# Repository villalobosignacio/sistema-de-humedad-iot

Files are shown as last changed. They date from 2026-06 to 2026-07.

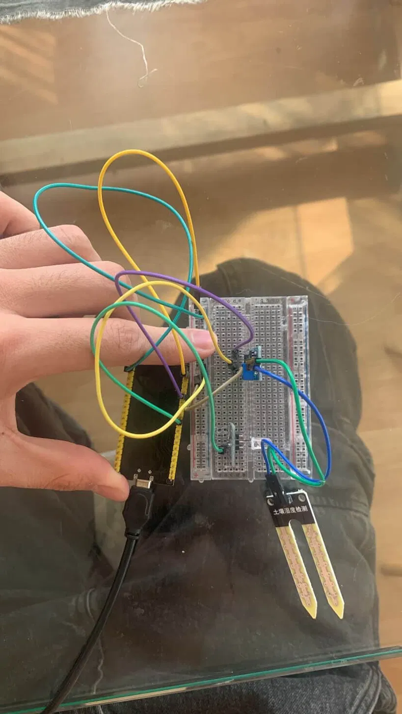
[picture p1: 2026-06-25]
hardware/1 foto.webp

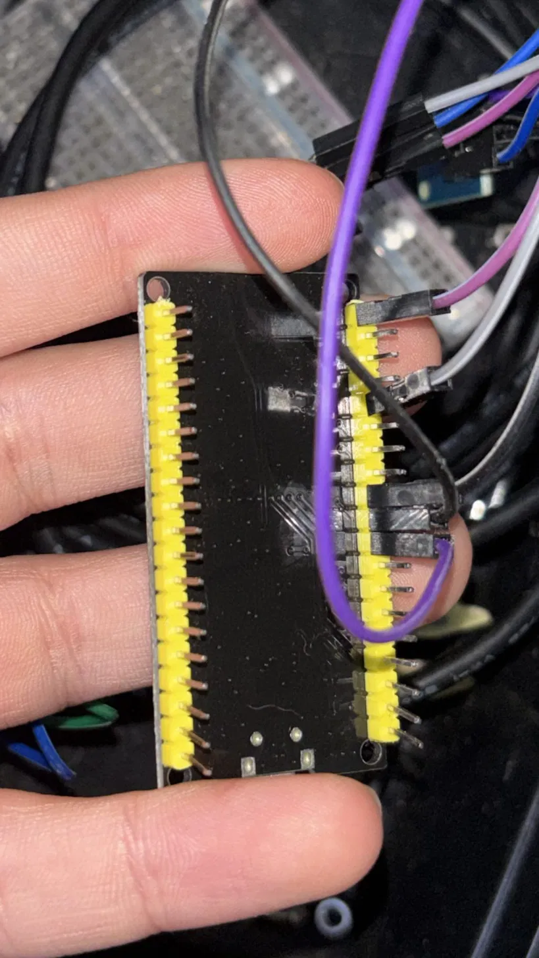
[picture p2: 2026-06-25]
hardware/2 foto.webp

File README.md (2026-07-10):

Sistema de Monitoreo de Humedad de Suelo

Sistema IoT que monitorea la humedad del suelo en tiempo real mediante un sensor resistivo conectado a un ESP32. El dispositivo indica el estado del suelo a través de LEDs de colores y registra las lecturas en el monitor serie, permitiendo tomar decisiones de riego oportunas.

Integrantes
Nicolas Oliden 
Benjamin Pizarro 
Ignacio Villalobos 
Emmanuel Poulangeon 

Curso: TEI201 — Taller de Diseño en Ingeniería  
Universidad: Universidad Adolfo Ibáñez  
Año:2026

Problema que resuelve

En hogares y espacios urbanos de Chile, el riego de plantas se realiza de forma intuitiva y sin información objetiva sobre el estado real del suelo. Esto genera dos problemas frecuentes: el riego excesivo, que desperdicia agua y daña las raíces por saturación, y la falta de riego oportuno, que provoca la muerte de las plantas. Nuestro sistema elimina esta incertidumbre entregando una señal visual inmediata sobre el nivel de humedad del suelo, permitiendo al usuario regar solo cuando es necesario.  
El sistema permite a cualquier persona saber si una planta necesita riego sin necesidad de medir manualmente la humedad del suelo. Un LED rojo indica tierra seca (riego urgente), amarillo indica humedad media, y verde indica tierra bien regada.

Componentes de hardware necesarios

| Componente | Cantidad | Especificación |

Componentes de hardware necesarios

| Componente | Cantidad | Especificación |
| ESP32 NodeMCU | 1 | microcontrolador con Wi-Fi integrado, ADC 12-bit |
| Sensor humedad suelo | 1 | Módulo LM393 (Sonda resistiva) — Conectado a pin GPIO 34 |
| Protoboard 400 pts | 1 | Para el montaje y orden de conexiones internas |
| Cables jumper | 10 | Conexiones internas de señal y alimentación |
| Cable USB micro | 1 | Para suministro eléctrico continuo y programación |
| Filamento PLA | ~50g | Material para la manufactura de la carcasa protectora 3D |

Ver BOM completo con costos en `/hardware/BOM.md`

Instrucciones para cargar el firmware

Requisitos previos
Arduino IDE 2.x instalado
Soporte para ESP32 instalado en el Board Manager:
Ir a **Archivo → Preferencias**
En "URLs adicionales" agregar: `https://raw.githubusercontent.com/espressif/arduino-esp32/gh-pages/package_esp32_index.json`
Ir a Herramientas → Placa → Gestor de placas → buscar "esp32" → Instalar

Pasos
1. Clonar este repositorio:
   ```
   git clone https://github.com/villalobosignacio/sistema-de-humedad-iot.git
   ```
2. Abrir `firmware/main.ino` en Arduino IDE
3. Conectar el ESP32 por USB
4. Seleccionar la placa: Herramientas → Placa → ESP32 Arduino → ESP32 Dev Module
5. Seleccionar el puerto COM correspondiente en Herramientas → Puerto
6. Subir el código con el botón Upload(→)
7. Abrir Monitor Serie a 115200 baudios para ver las lecturas en tiempo real

Lógica de indicación LED

| Color LED | Valor ADC | Estado del suelo |

| Rojo | 3000 – 4095 | Tierra seca — necesita riego |
| Amarillo (R+G) | 2000 – 2999 | Humedad media |
| Verde | 0 – 1999 | Tierra húmeda / bien irrigada |

Dashboard y Visualización
Los datos capturados por el ESP32 se envían mediante peticiones HTTPS (POST) a nuestra propia API alojada en Railway. 

[Acceder a la API/Dashboard en Railway](https://sistema-de-humedad-iot-production.up.railway.app/api/medicion)

Estructura del repositorio

```
sistema-de-humedad-iot/
│
├── README.md
├── FUENTES.md
│
├── firmware/
│   └── main.ino
│
├── hardware/
│   ├── BOM.md
│   ├── esquematico.pdf
│   ├── foto_prototipo_1.jpg
│   ├── foto_prototipo_2.jpg
│   └── foto_prototipo_3.jpg
│
├── diseño-3d/
│   ├── encapsulado.f3d
│   ├── planos.pdf
│   └── renders/
│
├── testing/
│   └── protocolo_pruebas.md
│
└── docs/
    └── reporte_final.pdf
```

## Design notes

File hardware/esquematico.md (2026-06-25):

Esquemático del circuito

Diagrama interactivo en Wokwi (incluye ESP32, sensor de humedad y LEDs):

Esquemático en Wokwi:https://wokwi.com/projects/462746890644844545

Componentes conectados
ESP32 NodeMCU
Sensor de humedad resistivo → GPIO34
LED Rojo → GPIO25 + resistencia 220Ω
LED Verde → GPIO26 + resistencia 220Ω  
LED Azul → GPIO27 + resistencia 220Ω

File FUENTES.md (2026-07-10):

Declaración de Fuentes y Herramientas

Proyecto: Sistema de Monitoreo de Humedad de Suelo IoT
Curso: TEI201 — Taller de Diseño en Ingeniería
Integrantes: Nicolas Oliden, Benjamin Pizarro, Ignacio Villalobos, Emmanuel Poulangeon

1. Librerías utilizadas

El proyecto utiliza las siguientes librerías del núcleo de ESP32 para habilitar la lectura analógica y la conectividad a internet:

| Función / Módulo | Origen | Uso en el proyecto |
| `WiFi.h` | Arduino ESP32 Core | Conexión del microcontrolador a la red Wi-Fi local. |
| `HTTPClient.h` | Arduino ESP32 Core | Creación y envío de peticiones HTTP POST al servidor. |
| `WiFiClientSecure.h` | Arduino ESP32 Core | Manejo de la conexión segura (HTTPS) para interactuar con la API en Railway. |
| `analogRead()` | Arduino ESP32 Core | Lectura del sensor de humedad de suelo en el pin 34. |

2. Código externo adaptado

No se utilizaron fragmentos de código de fuentes externas (GitHub, Stack Overflow, tutoriales, etc.). La estructura de conexión Wi-Fi y las peticiones HTTP fueron desarrolladas por el equipo con asistencia de Inteligencia Artificial.

3. Uso de Inteligencia Artificial

Desarrollo del Firmware (C++)
Herramientas: Claude y Gemini.
Uso:Asistencia en la reestructuración del código para evolucionar de un sistema local a un prototipo IoT conectado. Generación de la lógica para el armado del string JSON y el envío de la petición POST segura (`clienteSeguro.setInsecure()`) a la API alojada en Railway.
Comprensión del equipo: El equipo comprende completamente el flujo de datos: el sensor lee el valor analógico en el pin 34, la función `map()` lo convierte a un porcentaje (0-100%), se construye el payload en formato JSON y se envía mediante protocolo HTTPS a la ruta `/api/medicion`.

Documentación (README.md)
Herramientas: Claude.
Uso: Generación del template base del `README.md`; el contenido técnico específico fue completado por el equipo.

4. Recursos de referencia

| Recurso | URL | Uso |
| Documentación ESP32 Arduino Core | https://docs.espressif.com/projects/arduino-esp32/en/latest/ | Referencia para el pinout del ESP32 y funciones analógicas. |
| Railway Documentation | https://docs.railway.app/ | Referencia para el despliegue y recepción de datos en la API. |

*Declaración preparada en cumplimiento de los requisitos de integridad académica del curso TEI201 — UAI.*

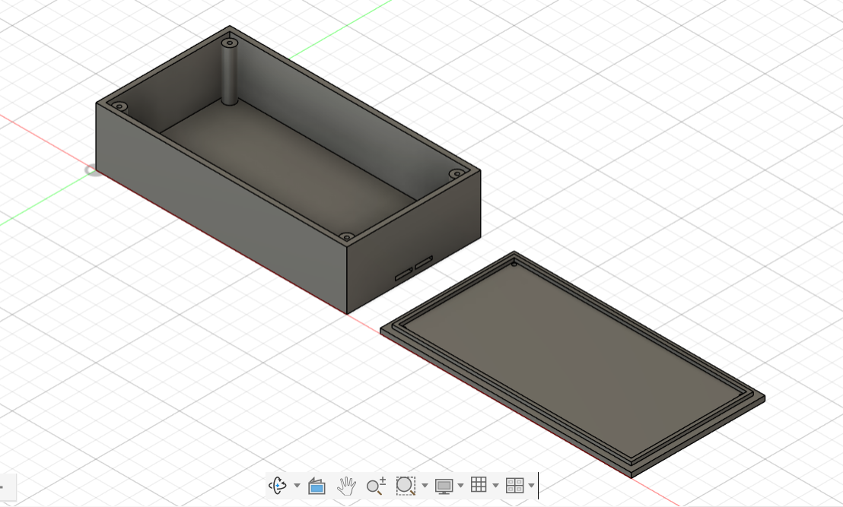
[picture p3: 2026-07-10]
diseño-3d/renders/Captura de pantalla 2026-07-09 182423.png

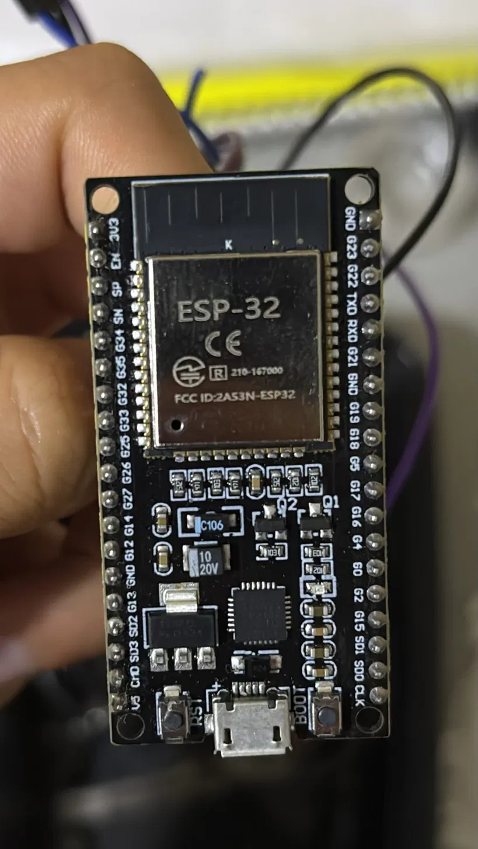
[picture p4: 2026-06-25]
hardware/3 foto.webp

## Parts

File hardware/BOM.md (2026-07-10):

BOM — Lista de Materiales

Proyecto: Sistema de Monitoreo de Humedad de Suelo IoT  
Curso: TEI201 — UAI 2026  
Integrantes: Nicolas Oliden, Benjamin Pizarro, Ignacio Villalobos, Emmanuel Poulangeon

| N° | Componente | Cantidad | Especificación técnica | Costo unitario (CLP) | Costo total (CLP) |
| 1 | ESP32 NodeMCU | 1 | ESP-32 38 pines, Wi-Fi + Bluetooth, dual core 240MHz, ADC 12-bit | $8.500 | $8.500 |
| 2 | Sensor humedad de suelo | 1 | Módulo LM393, salida analógica, rango 0–4095 ADC | $1.800 | $1.800 |
| 3 | Protoboard | 1 | 400 puntos, para montaje de pines internos | $2.500 | $2.500 |
| 4 | Cables jumper | 10 | Macho-hembra / Macho-macho, 20cm | $150 | $1.500 |
| 5 | Cable USB micro | 1 | Micro-USB, datos + alimentación (energía del sistema) | $1.500 | $1.500 |
| 6 | Filamento PLA (Impresión 3D) | ~50g | Material para la manufactura de la carcasa protectora | $20/gramo | $1.000 |
| TOTAL | | | | | $16.800 |

Justificación de componentes principales

ESP32 NodeMCU: Seleccionado estratégicamente por su módulo Wi-Fi integrado, el cual es el núcleo de nuestro sistema IoT. Permite capturar la lectura analógica de la tierra con precisión (ADC de 12 bits) y procesar el envío de datos en formato JSON de forma segura (HTTPS) hacia nuestra API en Railway.
Sensor resistivo de humedad: Seleccionado por disponibilidad, bajo costo y compatibilidad directa con el pin 34 del ESP32. La variación de la conductividad de la tierra se traduce en un nivel de voltaje que el microcontrolador mapea de 0 a 100%.
Carcasa impresa en 3D (PLA): Pieza diseñada a medida y parametrizada para encapsular de forma segura el microcontrolador y el cableado, protegiendo la electrónica y manteniendo expuesta únicamente la sonda que va insertada en el sustrato.

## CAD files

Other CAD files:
diseño-3d/caja sensor examen.f3d

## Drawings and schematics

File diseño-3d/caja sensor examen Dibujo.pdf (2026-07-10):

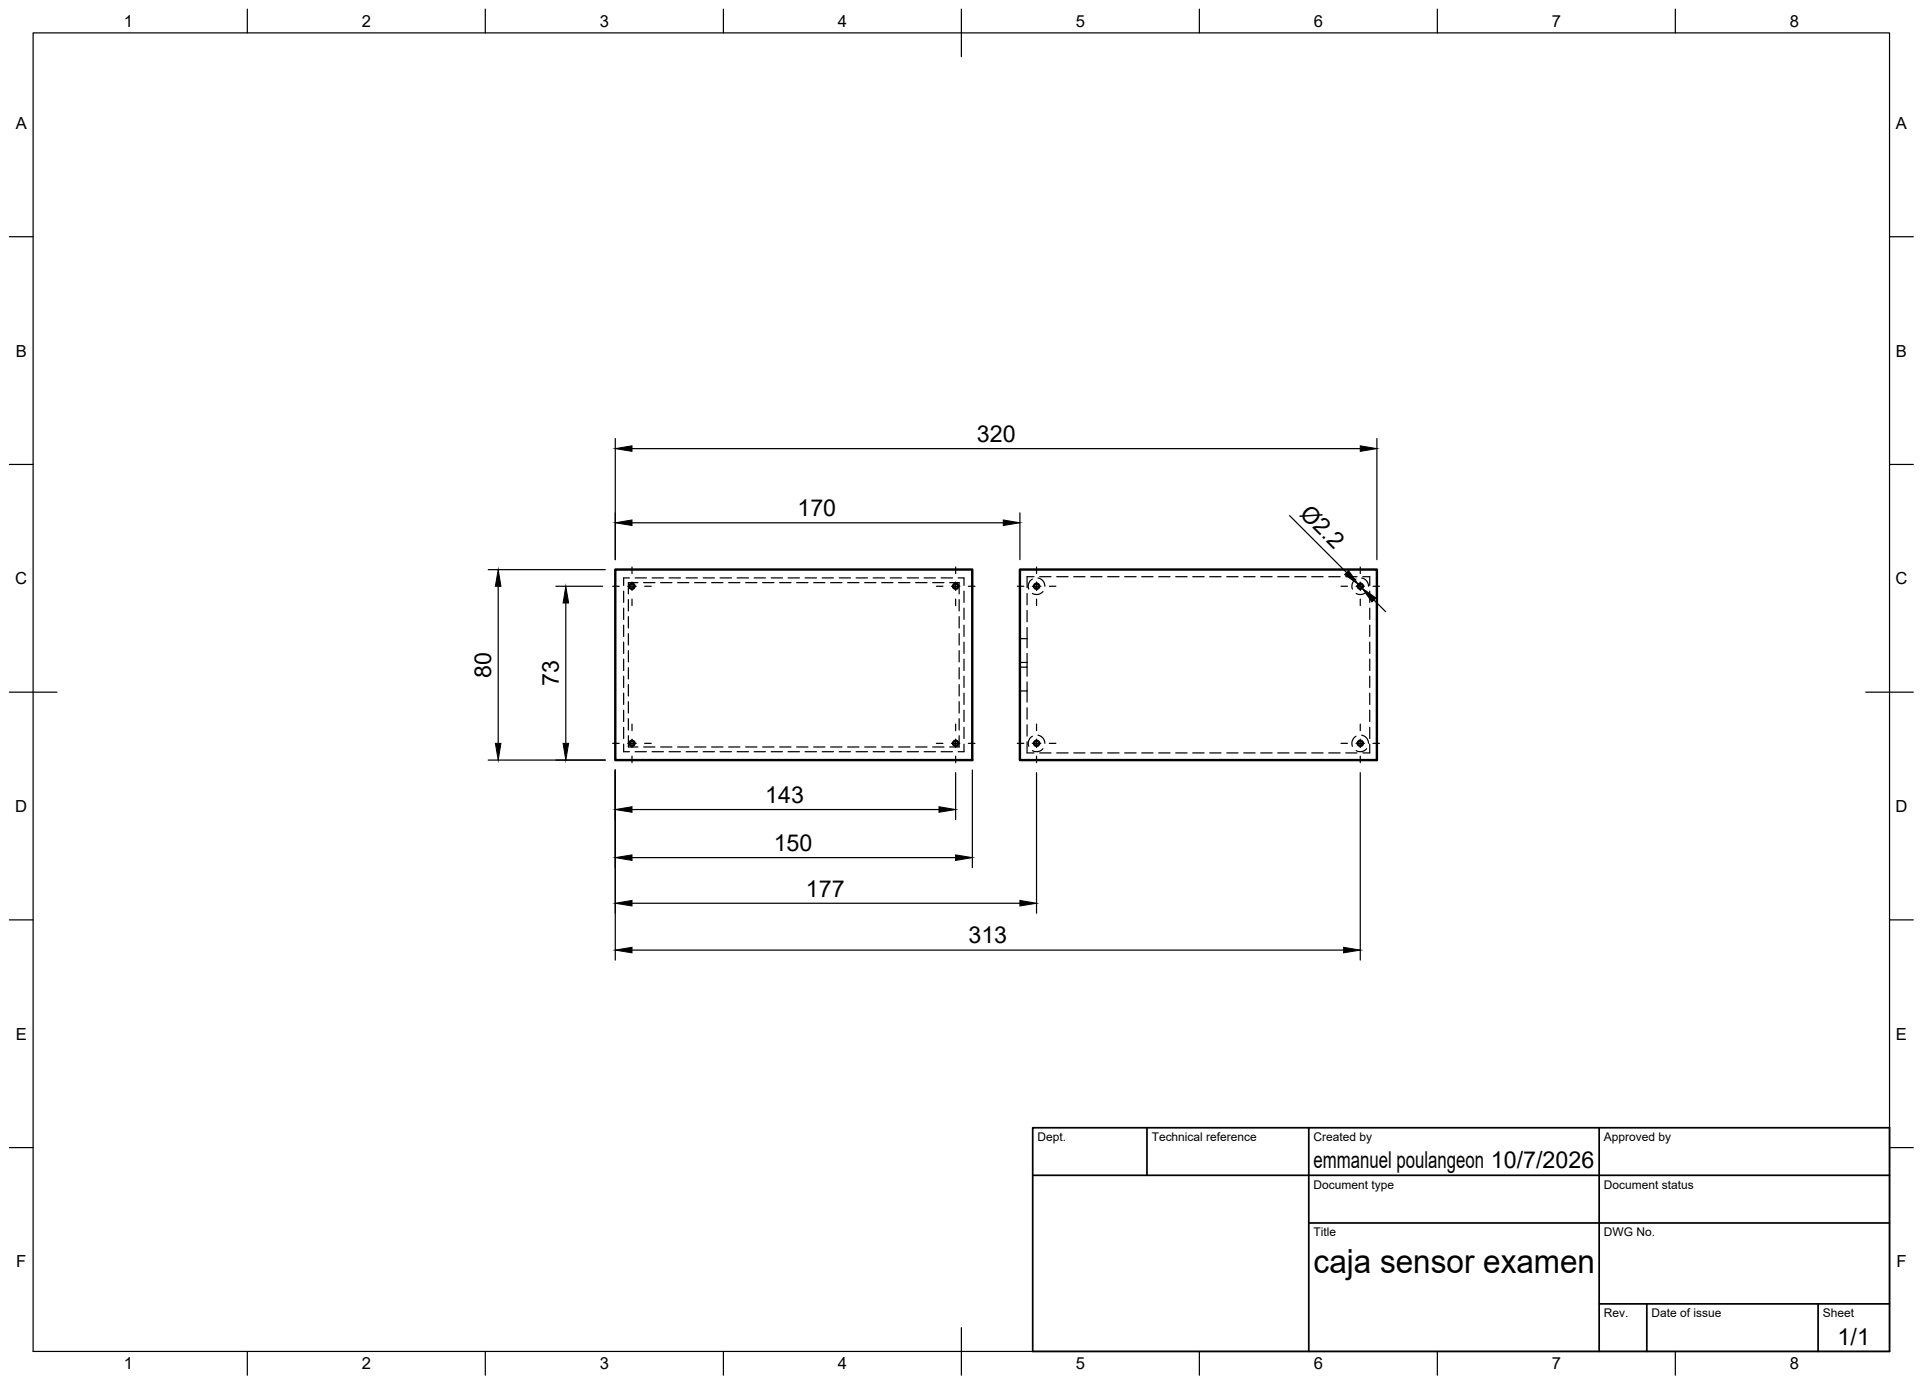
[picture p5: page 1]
Title; DWG No.; Rev.; Date of issue; Sheet

Dept. | Technical reference | Created by emmanuel poulangeon 10/7/2026 | Approved by

Document type | Document status

caja sensor examen

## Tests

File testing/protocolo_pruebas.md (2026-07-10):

Protocolo de Pruebas Sistema de Monitoreo de Humedad de Suelo IoT

Proyecto: Sistema de Monitoreo de Humedad de Suelo IoT  
Curso: TEI201 UAI 2026  
Integrantes: Nicolas Oliden, Benjamin Pizarro, Ignacio Villalobos, Emmanuel Poulangeon  
Fecha de pruebas: Julio 2026

Condiciones generales
* Dispositivo alimentado por USB.
* Monitor Serie abierto a 115200 baudios para verificar peticiones HTTP.
* Conexión a red Wi-Fi local establecida de forma estable.
* Sensor insertado verticalmente en el sustrato de prueba.

Prueba 1 — Detección de tierra seca y envío a API
Objetivo: Verificar que el sistema detecta correctamente suelo seco, mapea el porcentaje y envía la alerta al servidor mediante HTTPS.

Procedimiento:
1. Conectar el ESP32 a la energía y verificar conexión Wi-Fi.
2. Insertar el sensor en tierra completamente seca (o sostenerlo en el aire).
3. Esperar a que se ejecute la lectura y se arme el JSON.
4. Verificar la respuesta del servidor en el Monitor Serie o en el dashboard de Railway.

Criterio de éxito: Humedad calculada < 40% | JSON incluye "riegoRecomendado": true | Servidor responde con Código HTTP 200 o 201.

Resultado obtenido:
| Intento | Lectura Cruda | Humedad (%) | Estado en JSON | Código HTTP | ¿Correcto? |
| 1 | 4095 | 0% | Muy seco | 200 | Sí |

Prueba 2 — Detección de humedad media
Objetivo: Verificar que el sistema detecta suelo con humedad intermedia y actualiza el estado correctamente en la nube.

Procedimiento:
1. Tomar tierra seca y agregar agua en cantidad moderada.
2. Mezclar hasta obtener tierra húmeda pero no encharcada.
3. Insertar el sensor y esperar el intervalo de 10 segundos.

Criterio de éxito: Humedad calculada entre 40% y 79% | JSON incluye "Humedad media" o "No necesita riego" | Código HTTP 200.

Resultado obtenido:
| Intento | Lectura Cruda | Humedad (%) | Estado en JSON | Código HTTP | ¿Correcto? |
| 1 | 2650 | 50% | Humedad media | 200 | Sí |

Prueba 3 — Detección de tierra saturada
Objetivo: Verificar que el sistema detecta suelo bien irrigado y registra que no se requiere intervención.

Procedimiento:
1. Agregar agua abundante a la tierra hasta saturarla.
2. Insertar el sensor completamente en el sustrato.
3. Esperar lectura y registrar el comportamiento de la petición POST.

Criterio de éxito: Humedad calculada ≥ 80% | JSON incluye "Muy mojado" | Código HTTP 200.

Resultado obtenido:
| Intento | Lectura Cruda | Humedad (%) | Estado en JSON | Código HTTP | ¿Correcto? |
| 1 | 1200 | 100% | Muy mojado | 200 | Sí |

image (1)

Prueba 4 — Estabilidad de transmisión IoT
Objetivo: Verificar que el sistema realiza lecturas y peticiones HTTP cada 10 segundos de forma continua sin caídas del microcontrolador.

Procedimiento:
1. Dejar el sensor en una condición fija.
2. Observar el Monitor Serie o los logs de Railway durante 2 minutos.
3. Contar las peticiones exitosas recibidas por la API.

Criterio de éxito: Nueva petición POST enviada y confirmada cada 10 segundos sin reinicios del ESP32.

Resultado obtenido:
* Lecturas enviadas en 2 minutos: 12
* Intervalo promedio de transmisión: 10 segundos
* ¿Hubo interrupciones de Wi-Fi o reinicios? No.

Falla detectada y solución

Falla 1 (Física): Durante las pruebas, el sensor entregaba valores inestables al estar en tierra con piedras.
Causa: El sensor requiere contacto completo de las dos puntas. Materiales aislantes interfieren la resistencia.
Solución: Se definió que el sensor debe insertarse en tierra suelta.

Falla 2 (Software): Caídas eventuales de la red Wi-Fi bloqueaban el envío de datos permanentemente.
Causa: El código original no contemplaba reconexión si el router perdía la señal un instante.
Solución: Se implementó una rutina de reconexión automática en la función `enviarMedicion()`, donde el ESP32 verifica `WiFi.status() != WL_CONNECTED` y reinicia la conexión antes de intentar enviar el JSON.

Validación contra el problema original (Avance 1)

El problema identificado en Avance 1 fue: En hogares urbanos de Chile, el riego de plantas se realiza sin información objetiva sobre el estado real del suelo, generando desperdicio de agua por riego excesivo o muerte de plantas por falta de riego oportuno.

Nuestras pruebas demuestran que el sistema evolucionó de una simple alerta local a una solución de monitoreo continuo (IoT). Al mapear los valores de resistencia a un porcentaje exacto (0-100%) y enviarlos mediante peticiones HTTPS a nuestra propia API en Railway, el usuario ya no depende de estar físicamente frente a la maceta para ver una luz LED. 

Esto responde al problema con un estándar tecnológico superior: elimina la incertidumbre del riego entregando datos centralizados y categorizados ("Necesita riego", "Humedad media", etc.). El usuario puede tomar decisiones objetivas desde cualquier dispositivo conectado, optimizando el uso del recurso hídrico con precisión.

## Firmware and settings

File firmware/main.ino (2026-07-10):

#include <WiFi.h>
#include <HTTPClient.h>
#include <WiFiClientSecure.h>

// =====================================================
// CONFIGURACIÓN WIFI
// =====================================================

const char* ssid = "TU_NOMBRE_WIFI";
const char* password = "TU_CLAVE_WIFI";

// =====================================================
// URL DEL DASHBOARD EN RAILWAY
// =====================================================

const char* serverUrl =
  "sistema-de-humedad-iot-production.up.railway.app;

// =====================================================
// CONFIGURACIÓN DEL SENSOR
// =====================================================

// Pin analógico conectado desde AO del LM393
const int SENSOR_PIN = 34;

// Valores iniciales de calibración.
// Más adelante puedes cambiarlos con tus lecturas reales.
//
// Tierra seca / aire = 0%
// Tierra muy mojada = 100%
const int valorSeco = 4095;
const int valorMojado = 1200;

// Enviar una medición cada 10 segundos
const unsigned long INTERVALO_ENVIO = 10000;

unsigned long ultimoEnvio = 0;

// =====================================================
// OBTENER ESTADO SEGÚN PORCENTAJE
// =====================================================

String obtenerEstado(int humedad) {
  if (humedad >= 80) {
    return "Muy mojado";
  }

  if (humedad >= 60) {
    return "No necesita riego";
  }

  if (humedad >= 40) {
    return "Humedad media";
  }

  if (humedad >= 20) {
    return "Necesita riego";
  }

  return "Muy seco";
}

// =====================================================
// DETERMINAR SI NECESITA RIEGO
// =====================================================

bool obtenerRiegoRecomendado(int humedad) {
  return humedad < 40;
}

// =====================================================
// CONECTAR A WIFI
// =====================================================

void conectarWiFi() {
  WiFi.mode(WIFI_STA);
  WiFi.begin(ssid, password);

  Serial.print("Conectando al WiFi");

  unsigned long tiempoInicio = millis();

  while (WiFi.status() != WL_CONNECTED) {
    delay(500);
    Serial.print(".");

    if (millis() - tiempoInicio >= 20000) {
      Serial.println();
      Serial.println("No se pudo conectar. Reintentando...");

      WiFi.disconnect();
      delay(1000);
      WiFi.begin(ssid, password);

      tiempoInicio = millis();
    }
  }

  Serial.println();
  Serial.println("WiFi conectado correctamente");

  Serial.print("Direccion IP del ESP32: ");
  Serial.println(WiFi.localIP());
}

// =====================================================
// LEER SENSOR Y CALCULAR PORCENTAJE
// =====================================================

int obtenerPorcentajeHumedad(int lecturaCruda) {
  int porcentaje = map(
    lecturaCruda,
    valorSeco,
    valorMojado,
    0,
    100
  );

  porcentaje = constrain(porcentaje, 0, 100);

  return porcentaje;
}

// =====================================================
// ENVIAR MEDICIÓN AL DASHBOARD
// =====================================================

void enviarMedicion(
  int lecturaCruda,
  int humedadPorcentaje,
  String estado,
  bool riegoRecomendado
) {
  if (WiFi.status() != WL_CONNECTED) {
    Serial.println("WiFi desconectado.");
    Serial.println("Intentando reconectar...");

    conectarWiFi();
  }

  WiFiClientSecure clienteSeguro;

  // Permite conexión HTTPS con Railway
  clienteSeguro.setInsecure();

  HTTPClient http;

  bool conexionIniciada = http.begin(clienteSeguro, serverUrl);

  if (!conexionIniciada) {
    Serial.println("No se pudo iniciar la conexion con el servidor.");
    return;
  }

  http.addHeader("Content-Type", "application/json");

  String json = "{";
  json += "\"lectura\":" + String(lecturaCruda) + ",";
  json += "\"humedad\":" + String(humedadPorcentaje) + ",";
  json += "\"estado\":\"" + estado + "\",";
  json += "\"riegoRecomendado\":";
  json += riegoRecomendado ? "true" : "false";
  json += ",";
  json += "\"caso\":\"Medicion real ESP32\",";
  json += "\"ubicacion\":\"Caja prototipo\",";
  json += "\"dispositivo\":\"ESP32 sensor humedad\"";
  json += "}";

  Serial.println();
  Serial.println("JSON enviado:");
  Serial.println(json);

  int codigoHTTP = http.POST(json);

  Serial.print("Codigo HTTP: ");
  Serial.println(codigoHTTP);

  if (codigoHTTP > 0) {
    String respuesta = http.getString();

    Serial.print("Respuesta del servidor: ");
    Serial.println(respuesta);

    if (codigoHTTP == 200 || codigoHTTP == 201) {
      Serial.println("Medicion enviada correctamente al dashboard.");
    } else if (codigoHTTP == 404) {
      Serial.println("Error 404: no existe /api/medicion en el servidor.");
    } else if (codigoHTTP == 500) {
      Serial.println("Error 500: problema interno del servidor.");
    } else {
      Serial.println("El servidor respondio, pero hubo un problema.");
    }
  } else {
    Serial.print("Error de conexion HTTP: ");
    Serial.println(http.errorToString(codigoHTTP));
  }

  http.end();
}

// =====================================================
// SETUP
// =====================================================

void setup() {
  Serial.begin(115200);
  delay(1000);

  pinMode(SENSOR_PIN, INPUT);

  Serial.println();
  Serial.println("==================================");
  Serial.println("SISTEMA SENSOR DE HUMEDAD");
  Serial.println("==================================");

  conectarWiFi();

  // Hace la primera medición inmediatamente
  ultimoEnvio = millis() - INTERVALO_ENVIO;
}

// =====================================================
// LOOP
// =====================================================

void loop() {
  if (millis() - ultimoEnvio >= INTERVALO_ENVIO) {
    ultimoEnvio = millis();

    int lecturaCruda = analogRead(SENSOR_PIN);

    int humedadPorcentaje =
      obtenerPorcentajeHumedad(lecturaCruda);

    String estado =
      obtenerEstado(humedadPorcentaje);

    bool riegoRecomendado =
      obtenerRiegoRecomendado(humedadPorcentaje);

    Serial.println();
    Serial.println("----------------------------------");

    Serial.print("Lectura cruda: ");
    Serial.println(lecturaCruda);

    Serial.print("Humedad: ");
    Serial.print(humedadPorcentaje);
    Serial.println("%");

    Serial.print("Estado: ");
    Serial.println(estado);

    Serial.print("Riego recomendado: ");
    Serial.println(riegoRecomendado ? "SI" : "NO");

    enviarMedicion(
      lecturaCruda,
      humedadPorcentaje,
      estado,
      riegoRecomendado
    );

    Serial.println("----------------------------------");
    Serial.println("Proxima medicion en 10 segundos.");
  }
}

//El codigo comienza con las directivas de preprocesamiento que son:

//SENSOR_PIN 34
//LED_ROJO 25
//LED_VERDE 26
//LED_AZUL 27
//Los cuales tienen don nombres asignados para por los mismo componentes pines físicos que esta conectados a la placa y tambien es fácil de recordar esto permite que si se quiere cambiar un cable de sitio,
//solo se tienenque modificar el numero en una linea, justo despues se declara la variable global int valorHumedad = 0;, que funciona como un contenedor donde guardaremos el número que el sensor nos entregue en cada lectura.



//Dentro de la función setup(), que se ejecuta solo una vez al encender el dispositivo, la línea Serial.begin(115200) activa la comunicación con el computador para que se puedan ver los datos en pantalla a una velocidad de 115200 baudios.

//Después están las tres lineas, pinMode(LED_..., OUTPUT) preparan los pines de los LEDs para enviar electricidad (salida), y la llamada a apagarLED() asegura que el sistema comience con todas las luces apagadas para evitar lecturas visuales erróneas al arranque.

//En el loop principal loop(), que se repite infinitamente, la ejecución empieza con valorHumedad = analogRead(SENSOR_PIN);, donde el microcontrolador mide el voltaje en el pin 34 y lo convierte en un número entre 0 y 4095. 
//Las líneas Serial.print y Serial.println muestran este valor en tu monitor serie para que puedas monitorearlo. 
//Posteriormente, entra la lógica condicional: primero, if (valorHumedad >= 3000 && valorHumedad <= 4095) verifica si la tierra está muy seca (valores altos), en cuyo caso ejecuta la función rojo() para encender esa luz y escribe un aviso de riego en el monitor.
//Si eso no se cumple, el else if (valorHumedad >= 2000 && valorHumedad < 3000) revisa si la humedad es intermedia, activando la función amarillo(). Finalmente, el else if (valorHumedad < 2000) detecta si la tierra está bien hidratada, activando la función verde().
//Al terminar estas comparaciones, se imprime una línea divisoria y el programa se detiene durante 10 segundos con delay(10000); antes de volver a empezar.

//Al final del archivo se encuentran las funciones auxiliares que definen los colores. En rojo(), amarillo() y verde(), se utilizan comandos digitalWrite(PIN, HIGH/LOW) para enviar o cortar la energía a cada pin. 
//Por ejemplo, en la función amarillo(), se activan simultáneamente el LED_ROJO y el LED_VERDE porque, en la mezcla de colores luz, la unión de rojo y verde produce amarillo. 
//La función apagarLED() simplemente pone todos los pines en LOW para cortar el paso de corriente y apagar el dispositivo visual.
